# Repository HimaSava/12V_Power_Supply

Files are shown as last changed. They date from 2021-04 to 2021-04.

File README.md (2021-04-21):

# 12V_Power_Supply

A simple AC-DC 12V Power Supply.

Needed a +12V and -12V power supply for my ECG project. Didnt find a cheap alternative and I didn't want be relient only on benchtop power supplies. So made one.

ECG Project:
https://github.com/HimaSava/Single_Lead_ECG_Machine

It is a simple 2-Layer board with a 220V to 15V (500mA) centre tapped transformer. A bridge rectifier followed by a few capacitors and 7812 & 7912 voltage regulators. 

Note: Dont use a 12V transformer. There is some voltage drop in the voltage rectifiers. With a 12V transformer the output voltage is 11.75V without load. Also there is no need for heat sinks as the regulators dont get very hot due to the low current.

PCB Layout:

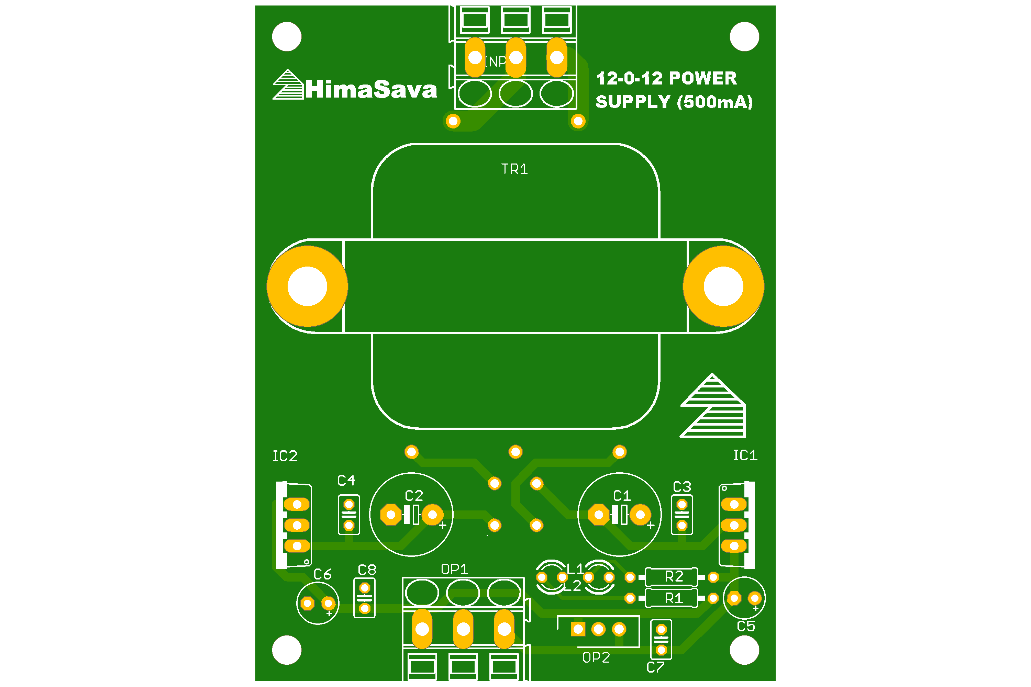
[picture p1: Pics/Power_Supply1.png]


Assembled Circuit:

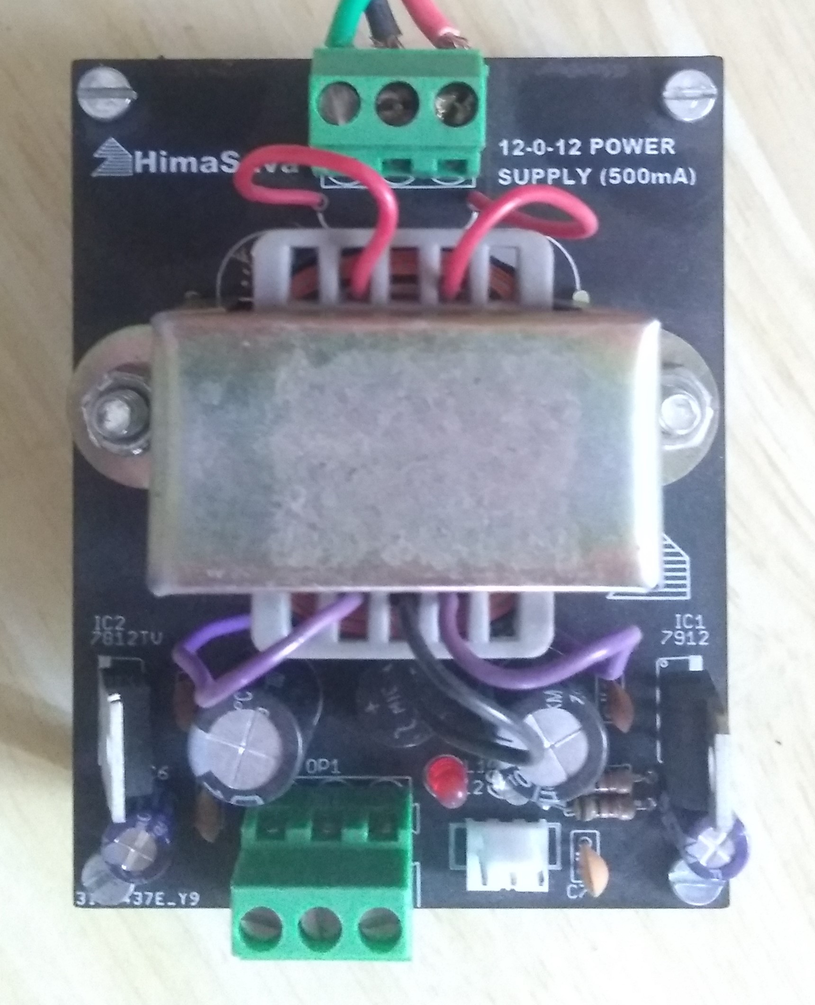
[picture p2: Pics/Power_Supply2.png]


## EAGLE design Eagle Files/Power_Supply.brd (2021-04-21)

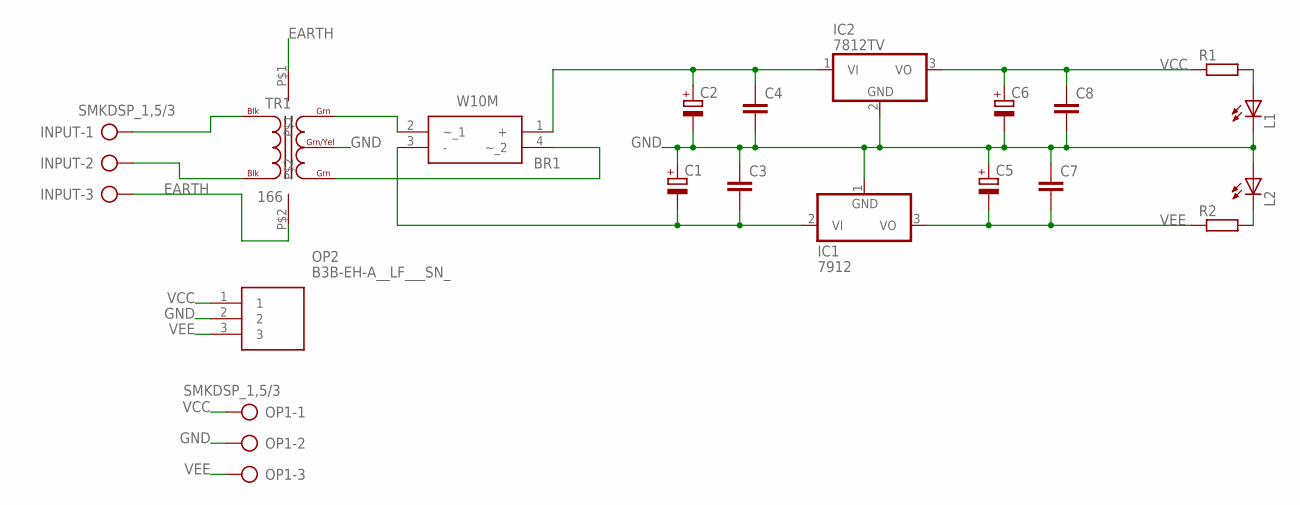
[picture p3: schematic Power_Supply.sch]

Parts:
BR1: W10M; WOM
C1, C2: CPOL-EUE5-10.5; E5-10,5
C3, C4, C7, C8: C-EU025-025X050; C025-025X050
C5, C6: CPOL-EUE2.5-5; E2,5-5
IC1: 7912; TO220V
IC2: 7812TV; TO220V
INPUT: SMKDSP_1,5/3
L1, L2: LED3MM
OP1: SMKDSP_1,5/3
OP2: B3B-EH-A__LF___SN_; SHDR3W64P0X250_1X3_1000X380X60
R1, R2: R-EU_0207/10; 0207/10
TR1: 166; C4H

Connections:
EARTH: INPUT.3, TR1.P$1, TR1.P$2
GND: C1.+, C2.-, C3.1, C4.2, C5.+, C6.-, C7.1, C8.2, IC1.1 (GND), IC2.2 (GND), L1.K (C), L2.A, OP1.2, OP2.2, TR1.GRN/YEL
unnamed: INPUT.1, TR1.BLK@1 (BLK)
unnamed: INPUT.2, TR1.BLK@2 (BLK)
unnamed: BR1.2 (~_1), TR1.GRN@1 (GRN)
unnamed: BR1.4 (~_2), TR1.GRN@2 (GRN)
unnamed: BR1.1 (+), C2.+, C4.1, IC2.1 (VI)
unnamed: BR1.3 (-), C1.-, C3.2, IC1.2 (VI)
unnamed: L2.K (C), R2.2
unnamed: L1.A, R1.2
VCC: C6.+, C8.1, IC2.3 (VO), OP1.1, OP2.1, R1.1
VEE: C5.-, C7.2, IC1.3 (VO), OP1.3, OP2.3, R2.1

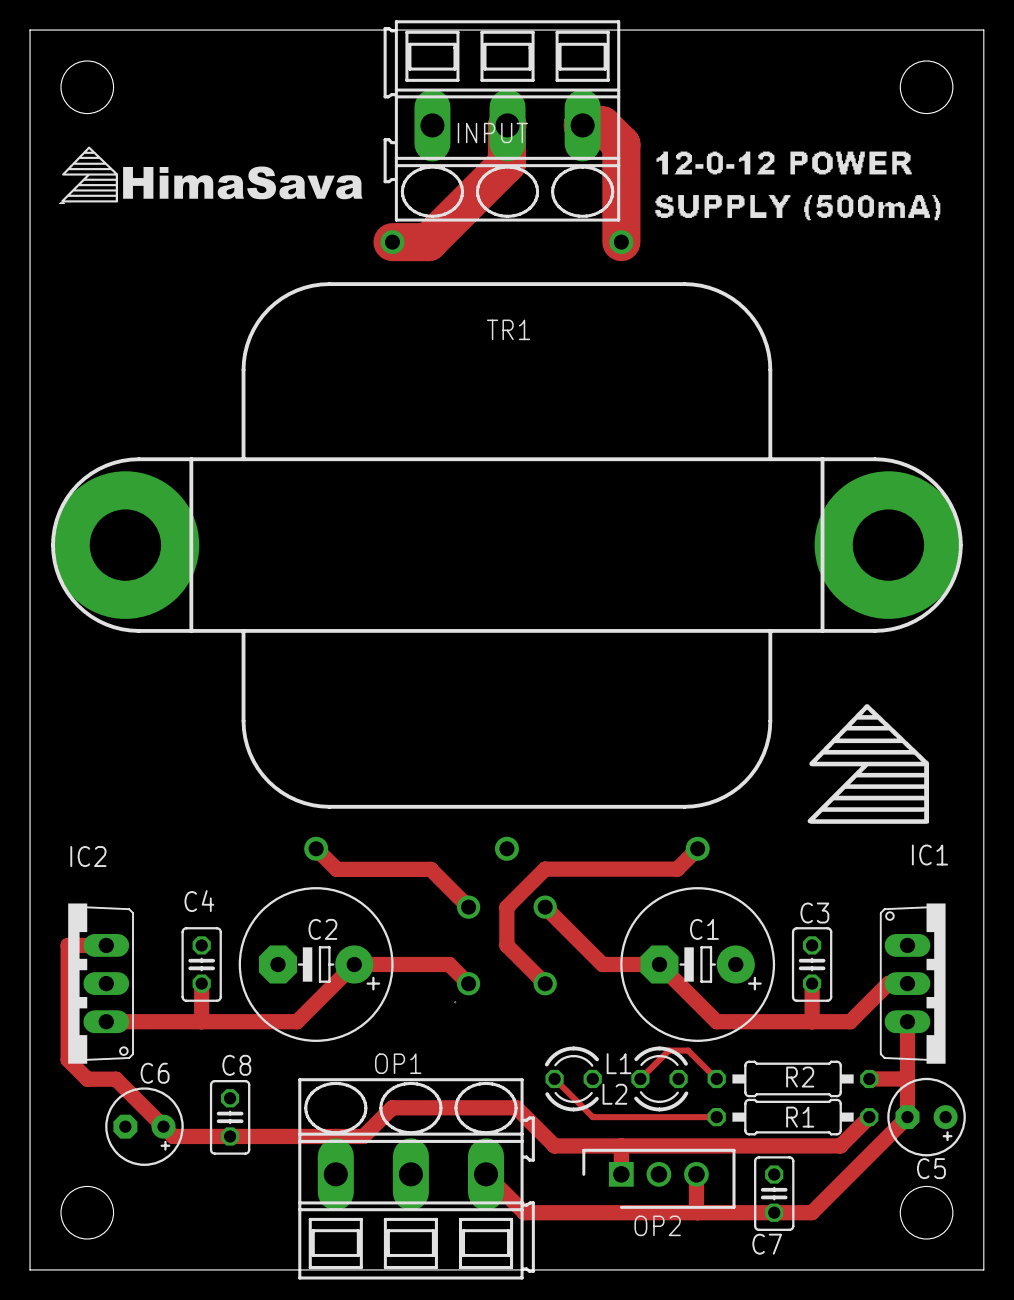
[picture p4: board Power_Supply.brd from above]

Board: 2 copper layers, 63.5 x 82.5 mm, 19 parts (0 on the bottom side), 12 nets.
